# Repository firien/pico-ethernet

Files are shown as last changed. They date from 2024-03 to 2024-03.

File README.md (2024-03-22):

https://github.com/firien/pico-contact-sensor

## Bill of Materials

|Tag|Qty|Value|Part|
|---|---|---|---|
|C1|1|22µF|https://www.digikey.com/en/products/detail/panasonic-electronic-components/EEE-FN1A220R/11656953|
|C2|1|10µF|https://www.digikey.com/en/products/detail/panasonic-electronic-components/EEE-HD1H100P/1985154|
|C5-6|2|30pF|https://www.digikey.com/en/products/detail/murata-electronics/GRM0335C1H300GA01D/4358722|
|C9|1|10µF|https://www.digikey.com/en/products/detail/samsung-electro-mechanics/CL10A106MQ8NNNC/3886777|
|C10,C7,C12,C4,C3,C11,C8|7|0.1µF|https://www.digikey.com/en/products/detail/murata-electronics/GRM033R60J104KE19D/702433|
|D1|1||https://www.digikey.com/en/products/detail/panjit-international-inc/MBR1020VL-R1-00001/14660471|
|FB1|1||https://www.digikey.com/en/products/detail/tai-tech-advanced-electronics-co-ltd/HFZ-1608PF-151T25/17835577|
|J1|1||https://www.digikey.com/en/products/detail/sullins-connector-solutions/PPTC201LFBN-RC/810158|
|J2|1||https://www.digikey.com/en/products/detail/sullins-connector-solutions/PPTC051LFBN-RC/807239|
|J3|1||https://www.digikey.com/en/products/detail/xp-power/VR05S05/13147728|
|J4|1||https://www.digikey.com/en/products/detail/bel-fuse-inc/SI-52003-F/1635087|
|J5|1||https://www.digikey.com/en/products/detail/phoenix-contact/1725672/267464|
|R1|1|2.32kΩ|https://www.digikey.com/en/products/detail/panasonic-electronic-components/ERJ-3EKF2321V/196189|
|R2-5|4|49.9Ω|https://www.digikey.com/en/products/detail/panasonic-electronic-components/ERJ-3EKF49R9V/196378|
|R6-7|2|180Ω|https://www.digikey.com/en/products/detail/panasonic-electronic-components/ERJ-3EKF1800V/1746322|
|U1|1||https://www.digikey.com/en/products/detail/microchip-technology/ENC28J60-I-SS/2296975|
|Y1|1|25MHz|https://www.digikey.com/en/products/detail/cts-frequency-controls/445I23E25M00000/3135168|

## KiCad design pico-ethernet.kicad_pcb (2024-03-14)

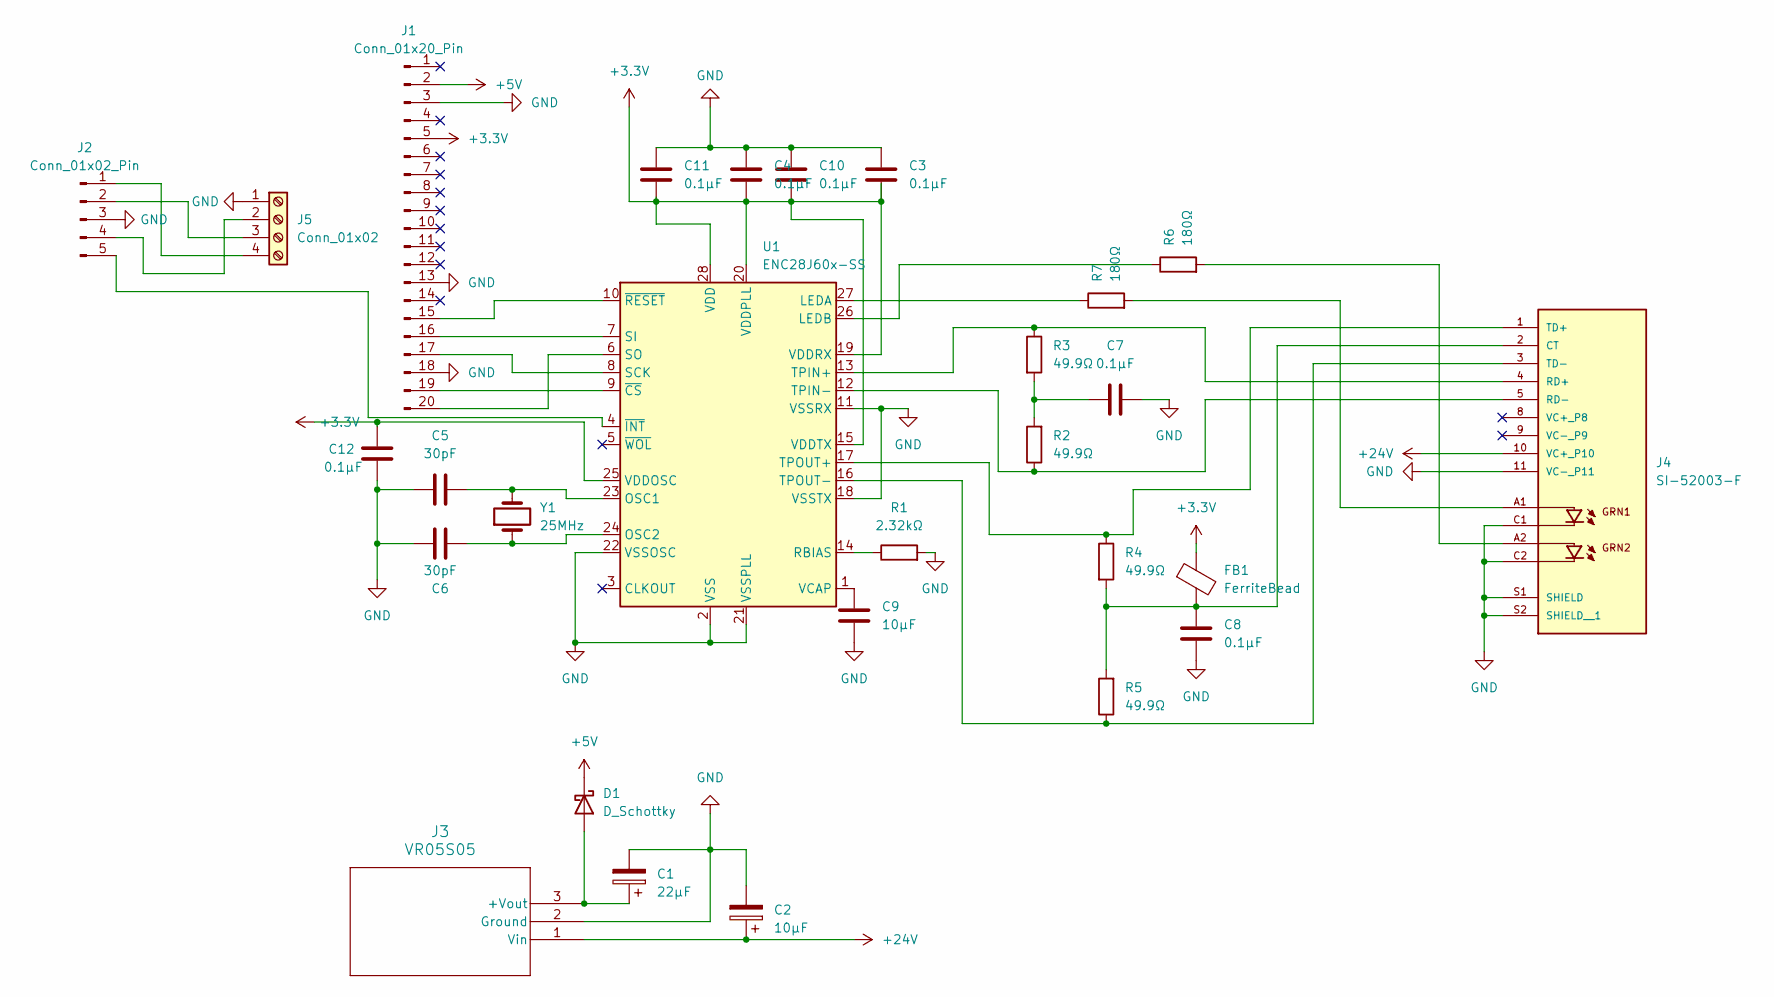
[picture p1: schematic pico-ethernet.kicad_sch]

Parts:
C1: 22µF; CAP_EEEFN1A220R
C2: 10µF; CAP_EEEHD1H100P
C3, C4, C7, C8, C10, C11, C12: 0.1µF; C_0603_1608Metric
C5, C6: 30pF; C_0603_1608Metric
C9: 10µF; C_0603_1608Metric
D1: D_Schottky; D_SOD-123
FB1: FerriteBead; C_0603_1608Metric
J1: Conn_01x20_Pin; PinSocket_1x20_P2.54mm_Vertical
J2: Conn_01x02_Pin; PinSocket_1x05_P2.54mm_Vertical
J3: VR05S05; CONN3_05S05_XPR
J4: SI-52003-F; BEL_SI-52003-F
J5: Conn_01x02; TerminalBlock_Phoenix_MPT-0,5-4-2.54_1x04_P2.54mm_Horizontal
R1: 2.32kΩ; R_0603_1608Metric
R2, R3, R4, R5: 49.9Ω; R_0603_1608Metric
R6, R7: 180Ω; R_0603_1608Metric
U1: ENC28J60x-SS; SSOP-28_5.3x10.2mm_P0.65mm
Y1: 25MHz; Crystal_SMD_5032-2Pin_5.0x3.2mm

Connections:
+3.3V: C3.1, C4.1, C10.1, C11.1, C12.2, FB1.1, J1.5, U1.15 (VDDTX), U1.19 (VDDRX), U1.20 (VDDPLL), U1.25 (VDDOSC), U1.28 (VDD)
+5V: D1.1 (K), J1.2
+24V: C2.1, J3.1 (Vin), J4.10 (VC+_P10)
GND: C1.2, C2.2, C3.2, C4.2, C5.1, C6.1, C7.2, C8.2, C9.2, C10.2, C11.2, C12.1, J1.3, J1.13, J1.18, J2.3, J3.2 (Ground), J4.11 (VC-_P11), J4.C1, J4.C2, J4.S1 (SHIELD), J4.S2 (SHIELD__1), J5.1, R1.2, U1.2 (VSS), U1.11 (VSSRX), U1.18 (VSSTX), U1.21 (VSSPLL), U1.22 (VSSOSC)
unnamed: C7.1, R2.2, R3.2
unnamed: C1.1, D1.2 (A), J3.3 (+Vout)
unnamed: J1.15, U1.10 (~RESET)
unnamed: J1.16, U1.7 (SI)
unnamed: J1.17, U1.8 (SCK)
unnamed: J1.19, U1.9 (~CS)
unnamed: J1.20, U1.6 (SO)
unnamed: J2.1, J5.4
unnamed: J2.2, J5.3
unnamed: J2.4, J5.2
unnamed: J2.5, U1.4 (~INT)
unnamed: C8.1, FB1.2, J4.2 (CT), R4.2, R5.2
unnamed: J4.A1, R7.2
unnamed: J4.A2, R6.2
unnamed: J4.4 (RD+), R3.1, U1.13 (TPIN+)
unnamed: J4.5 (RD-), R2.1, U1.12 (TPIN-)
unnamed: J4.1 (TD+), R4.1, U1.17 (TPOUT+)
unnamed: J4.3 (TD-), R5.1, U1.16 (TPOUT-)
unnamed: R7.1, U1.27 (LEDA)
unnamed: R6.1, U1.26 (LEDB)
unnamed: C5.2, U1.23 (OSC1), Y1.2
unnamed: C6.2, U1.24 (OSC2), Y1.1
unnamed: R1.1, U1.14 (RBIAS)
unnamed: C9.1, U1.1 (VCAP)

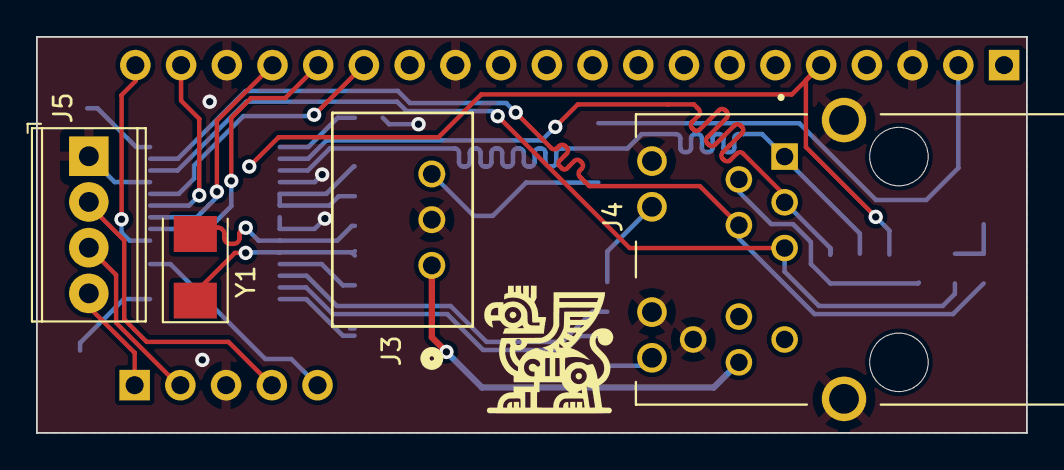
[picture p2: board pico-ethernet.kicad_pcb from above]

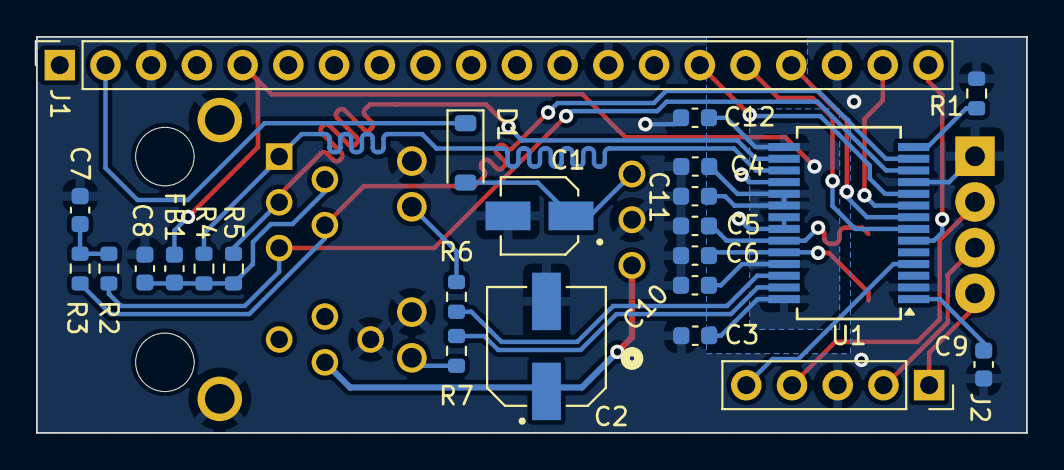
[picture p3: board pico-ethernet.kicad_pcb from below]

Board: 2 copper layers, 55.0 x 22.0 mm, 28 parts (24 on the bottom side), 28 nets.

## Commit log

2024-03-09 TX RX swap
    [pico-ethernet.kicad_pcb, pico-ethernet.kicad_sch]
2024-03-09 all good, but looks bad
    [pico-ethernet.kicad_pcb]
2024-03-09 3v reroute
    [pico-ethernet.kicad_pcb, pico-ethernet.kicad_sch]
2024-03-09 3v zone
    [pico-ethernet.kicad_pcb]
2024-03-10 tweak J2 position
    [pico-ethernet.kicad_pcb]
2024-03-10 bom update
2024-03-11 unnecessary tuning
    [pico-ethernet.kicad_pcb]
2024-03-12 connect reset
    [pico-ethernet.kicad_pcb, pico-ethernet.kicad_sch]
2024-03-12 move oscillator away from vias
    [pico-ethernet.kicad_pcb]
